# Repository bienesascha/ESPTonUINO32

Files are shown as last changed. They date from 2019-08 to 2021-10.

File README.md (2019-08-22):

# ESPTonUINO32
*ESPTonUINO32 V3.1.1 by M.Schwager*

- orginal [TonUINO-ESP32](http://discourse.voss.earth/t/esp32-port-inkl-webinterface/399)
_[TonUINO V2.0](https://www.voss.earth/tonuino/) Code for ESP32 with extensions, there is also [Discourse Seite](http://discourse.voss.earth/)_
- TonUNI-ESP32 V3.1 by C.Ulbrich, 

## *actual under development*
 - additional buttons
   - seperate buttons for next/last track / 5 button control

 - SDCard files  
   - Language menu and structure expanded to Tag to save Ambilight color
   - additional files added
   - sorting mp3 files

 - electric
   - actual schema
   - actual layout

 - 3d housing

**Currently implemented:**
  
  - Web interface for remote control
    - Play, Pause, Start, Stop, Volume
    - Adjust equalizer
    - max. Adjust Volume
    - Off timer
    - On timer
    
  - Ambientlight with WS2812 LEDss
    - change the color via web interface
    
  - Timer for switching on and off
    - Sunrise and sunset simulation for switch-on timer
    - MP3 playback when switching on / off
    
  - AP mode to configure WLAN without anchoring this (SSID, PW) in the code
    - Voice message if there is an error with the connection
   
  - Welcome at startup 
   
  - Headphone detection
    - reduces the volume when headphones plugged
    - Limit the volume when headphones are plugged
    - switches to previous volume when headphones are no longer plugged in
      
  - Function of the up-down keys changed
    - short press = Volume +/-
    - long press = Track +/- (unused if 5 buttons enabled)

  - Viual Studio Code mit platformio-code
    
 **Hardware / Layout**
  (http://hobbycomponents.com/images/forum/Wemos_Lolin_D32_Diagram_HCWEMO0014.png)
 
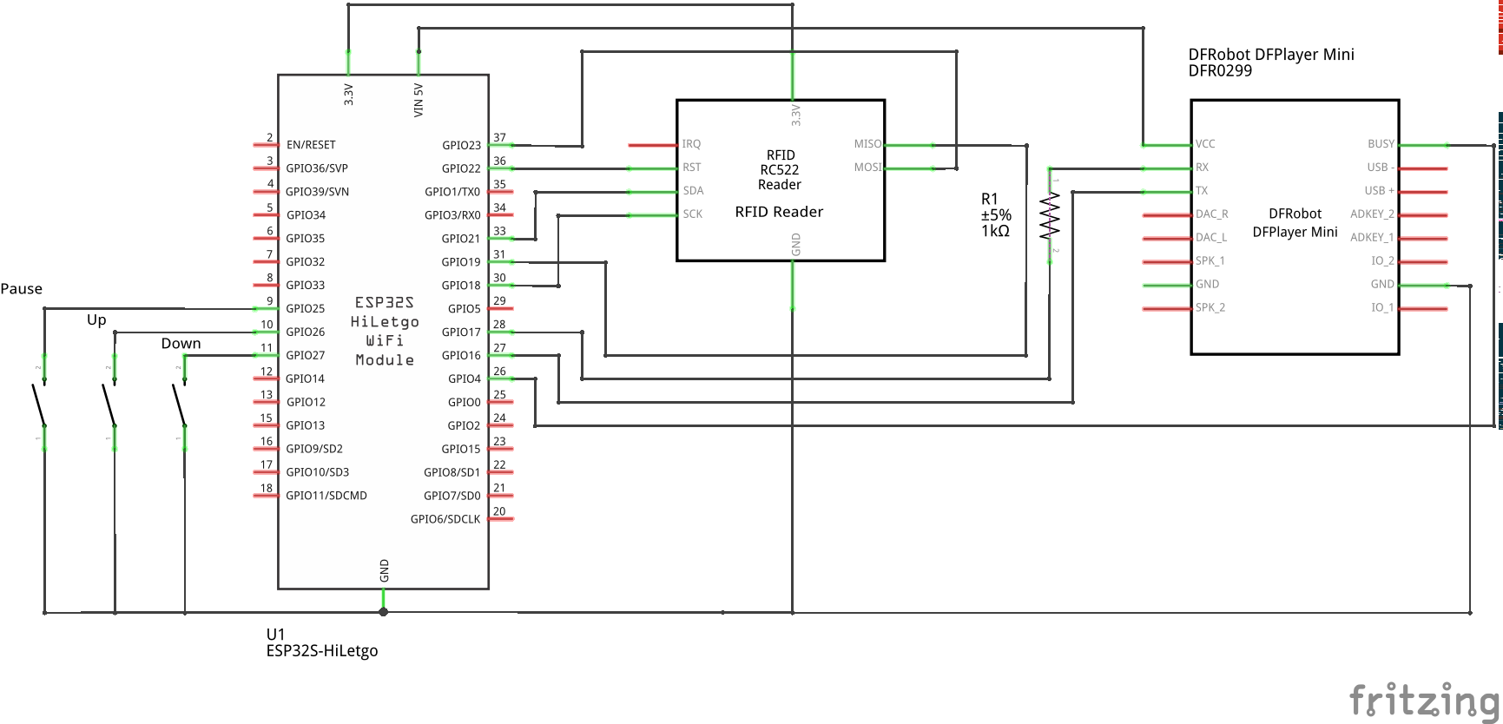
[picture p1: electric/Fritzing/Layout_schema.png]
fritzing Layout
 
 
 **Still open and planned:**
 
  - Saving the settings in EEPROM / Flash
  - Manage tags

  **additional goodies**

   - precompiles bin file

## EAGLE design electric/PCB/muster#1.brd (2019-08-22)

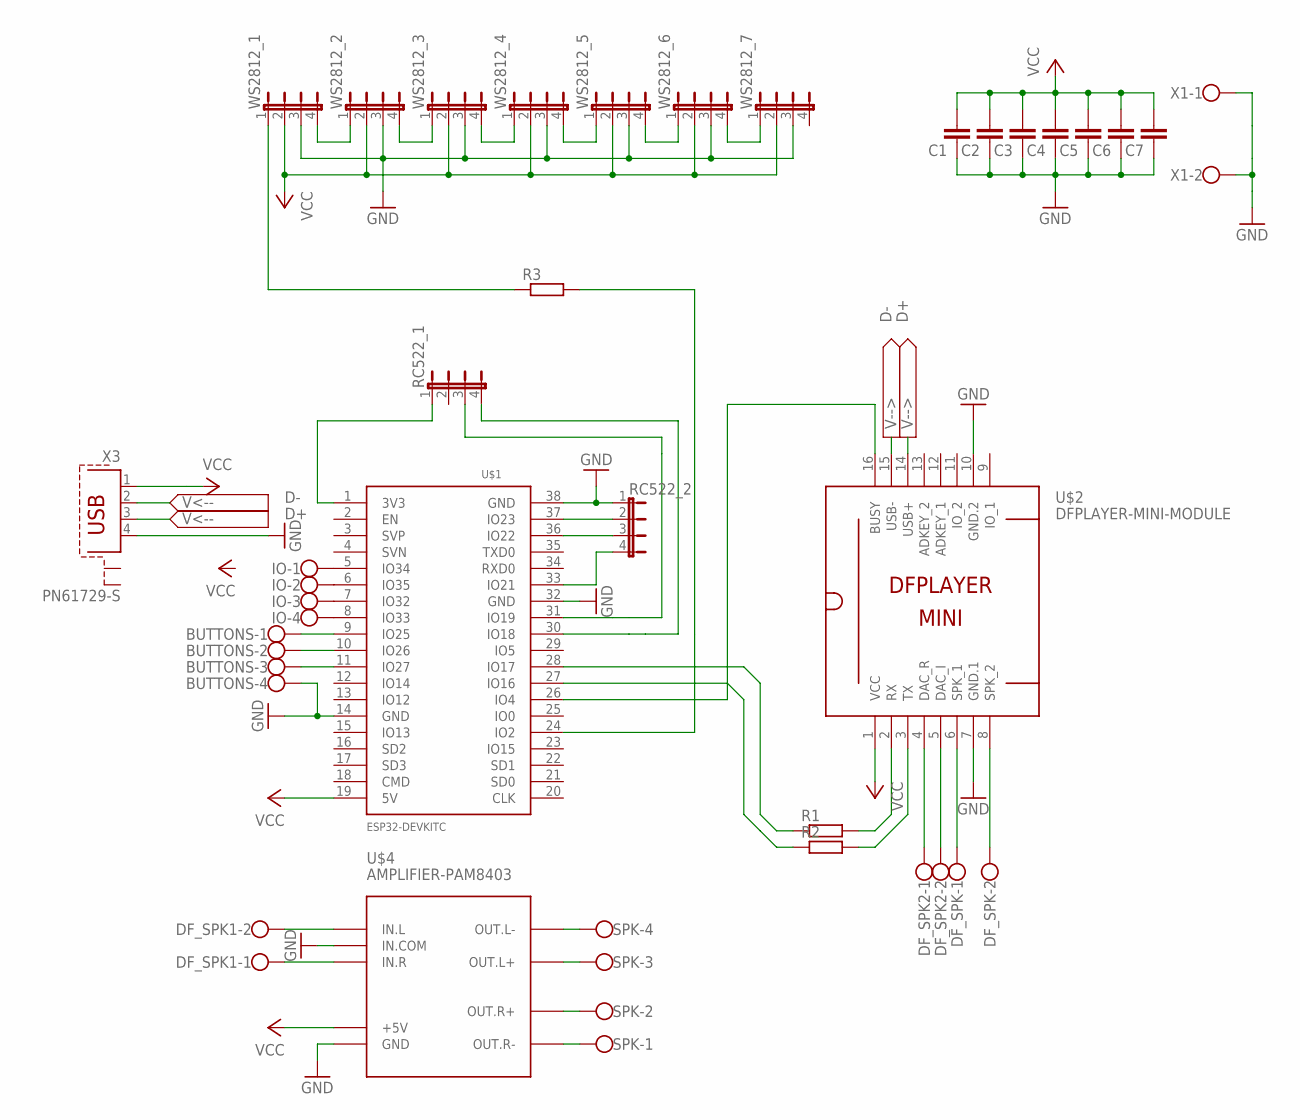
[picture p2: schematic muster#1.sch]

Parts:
BUTTONS: W237-4
C1: C-EU025-024X044; C025-024X044
C2, C3, C4, C5, C6, C7: C-EU025-025X050; C025-025X050
DF_SPK, DF_SPK1, DF_SPK2: W237-02P; W237-132
IO: W237-4
R1, R2, R3: R-EU_0204/2V; 0204V
RC522_1, RC522_2: JP4E; JP4
SPK: W237-4
U$1: ESP32DEVKITC; ESP32-DEVKITC
U$2: DFPLAYER-MINI-MODULE
U$4: AMPLIFIER-PAM8403
WS2812_1, WS2812_2, WS2812_3, WS2812_4, WS2812_5, WS2812_6, WS2812_7: JP4E; JP4
X1: W237-102
X3: PN61729-S

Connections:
D+: U$2.14 (USB+), X3.3
D-: U$2.15 (USB-), X3.2
GND: BUTTONS.4, C1.1, C2.1, C3.1, C4.1, C5.1, C6.1, C7.1, RC522_2.1, U$1.14 (GND), U$1.32 (GND), U$1.38 (GND), U$2.7 (GND.1), U$2.10 (GND.2), U$4.GND, U$4.IN.COM, WS2812_1.3, WS2812_2.3, WS2812_3.3, WS2812_4.3, WS2812_5.3, WS2812_6.3, WS2812_7.3, X1.1, X1.2, X3.4
unnamed: DF_SPK.2, U$2.8 (SPK_2)
unnamed: DF_SPK.1, U$2.6 (SPK_1)
unnamed: BUTTONS.1, U$1.9 (IO25)
unnamed: BUTTONS.2, U$1.10 (IO26)
unnamed: BUTTONS.3, U$1.11 (IO27)
unnamed: R1.1, U$1.28 (IO17)
unnamed: R2.1, U$1.27 (IO16)
unnamed: R2.2, U$2.3 (TX)
unnamed: WS2812_1.4, WS2812_2.1
unnamed: WS2812_2.4, WS2812_3.1
unnamed: R1.2, U$2.2 (RX)
unnamed: SPK.1, U$4.OUT.R-
unnamed: DF_SPK2.1, U$2.4 (DAC_R)
unnamed: R3.1, WS2812_1.1
unnamed: SPK.2, U$4.OUT.R+
unnamed: SPK.3, U$4.OUT.L+
unnamed: SPK.4, U$4.OUT.L-
unnamed: WS2812_3.4, WS2812_4.1
unnamed: WS2812_4.4, WS2812_5.1
unnamed: WS2812_5.4, WS2812_6.1
unnamed: WS2812_6.4, WS2812_7.1
unnamed: DF_SPK2.2, U$2.5 (DAC_I)
unnamed: DF_SPK1.2, U$4.IN.L
unnamed: DF_SPK1.1, U$4.IN.R
unnamed: R3.2, U$1.24 (IO2)
unnamed: RC522_2.2, U$1.37 (IO23)
unnamed: U$1.26 (IO4), U$2.16 (BUSY)
unnamed: RC522_2.3, U$1.36 (IO22)
unnamed: RC522_2.4, U$1.33 (IO21)
unnamed: RC522_1.3, U$1.31 (IO19)
unnamed: RC522_1.4, U$1.30 (IO18)
unnamed: RC522_1.1, U$1.1 (3V3)
unnamed: IO.1, U$1.5 (IO34)
unnamed: IO.2, U$1.6 (IO35)
unnamed: IO.3, U$1.7 (IO32)
unnamed: IO.4, U$1.8 (IO33)
VCC: C1.2, C2.2, C3.2, C4.2, C5.2, C6.2, C7.2, U$1.19 (5V), U$2.1 (VCC), U$4.+5V, WS2812_1.2, WS2812_2.2, WS2812_3.2, WS2812_4.2, WS2812_5.2, WS2812_6.2, WS2812_7.2, X3.1

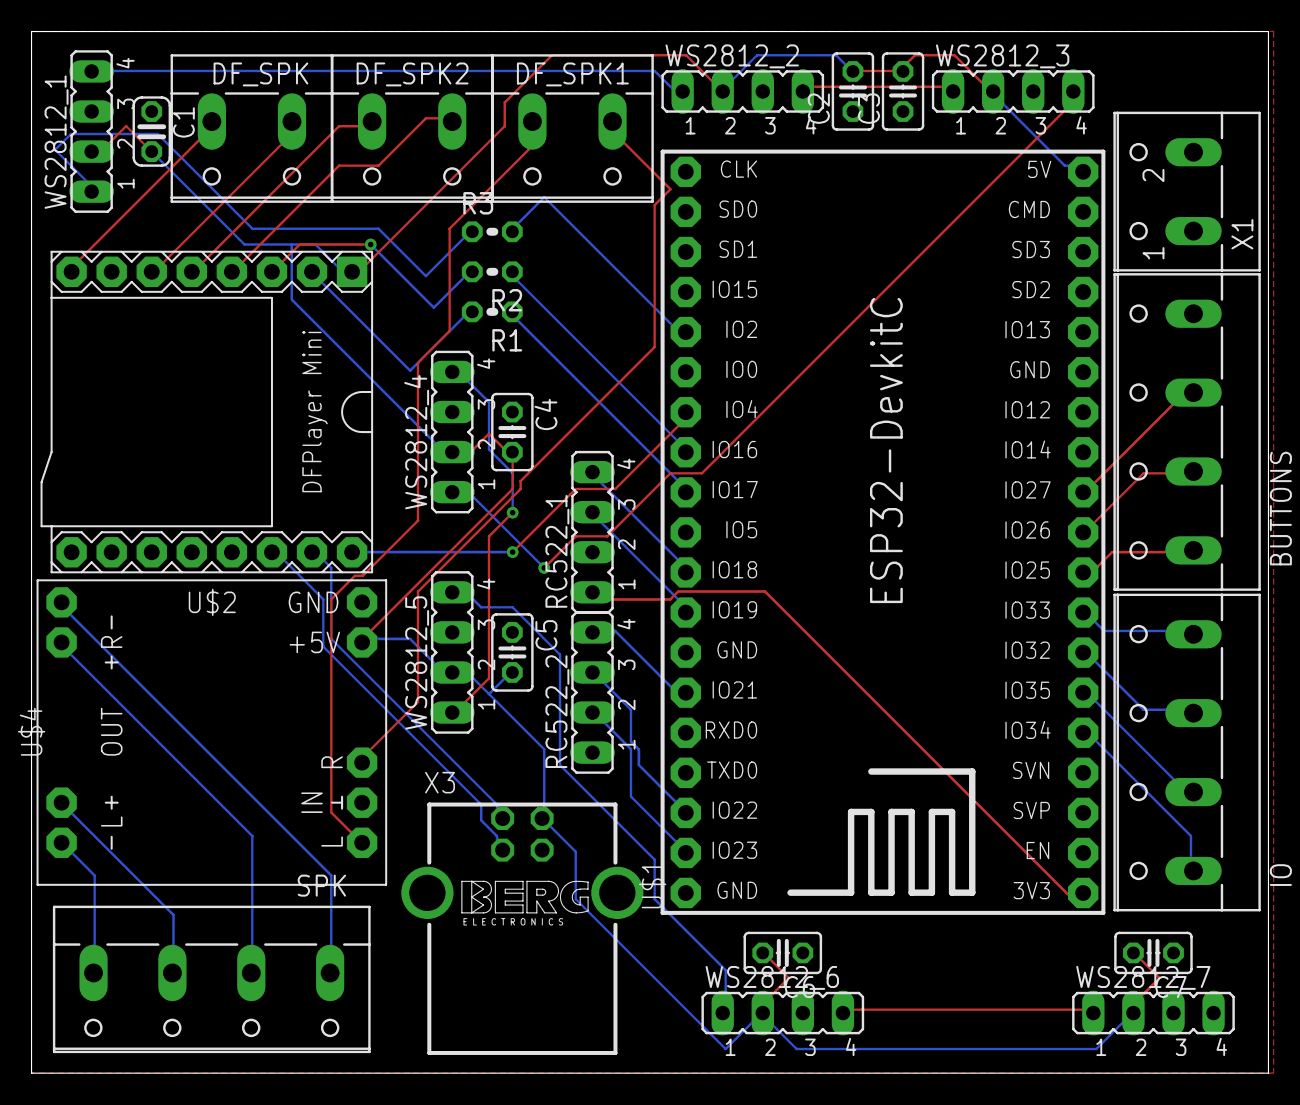
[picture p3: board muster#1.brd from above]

Board: 2 copper layers, 78.4 x 66.0 mm, 30 parts (0 on the bottom side), 40 nets.

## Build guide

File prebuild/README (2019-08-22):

This directory is only for pre-compiled-builds.

No warranty, no hardware checks

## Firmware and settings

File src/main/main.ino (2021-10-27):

//==================================================================
// ESPTonUINO32 V4.0.1 of ESP Lolin32
// changed by Sascha Ludwig
// 2021-10
// Original V2.0: T. Voss, Erweitert V3.0: C. Ulbrich
//------------------------------------------------------------------
// the DIY jukebox (not only) for kids
//
// Take an ESP lolin32, an MP3 module (DFPlayer mini), an RFID reader (RC522), 
// a micro SD card, Resistor, 3-5 buttons
// some cables and an old (or new) bookshelf speaker maybe a lipo bat...
// and you have the ESPTonUINO32 with charge controll and bat power
//==================================================================

// Used libraries

#include <WiFi.h>
#include <NTPClient.h>
#include <WiFiUdp.h>
#include "TonUINO_html.h"         // German version of html page
#include "TonUINO.h"  
#include <Arduino.h>
#include "DFRobotDFPlayerMini.h"
#include <SPI.h>
#include <MFRC522.h>
#include <EEPROM.h>
#include <JC_Button.h>
#include <math.h>
#include <FastLED.h>
#include <Update.h>
#include <WebServer.h>
#include <Preferences.h>
#include "define.h"

// EEPROM Storage *NVS*
// EEPROM_SIZE = EEPROM.length(); KO for ESP32
#define EEPROM_SIZE 4096
Preferences preferences;
int timeout = 20;

//========================================================================
// Only variables for testing
int l = 0;
bool headphoneIn = 1; //0;
int success = 0;
int success2 = 0;

bool debug = false; //false // Set to "true" to get debug information via the serial port.

//Variables for saving settings
//========================================================================
unsigned long last_color = 0xFFFFFF;
unsigned int last_Volume;
unsigned int last_max_Volume;

CRGB leds[NUM_LEDS];

//============Sunrise Variables===========================================
DEFINE_GRADIENT_PALETTE( sunrise_gp ) {
  0,     0,  0,  0,             // black
  128,   240,  0,  0,           // red
  224,   240, 240,  0,          // yellow
  255,   128, 128, 240
}; //very bright blue
static uint16_t heatIndex = 0; // start out at 0

//========================================================================
//NTP Variables
WebServer server(80);
WiFiUDP ntpUDP;
NTPClient timeClient(ntpUDP);

//========================================================================
// Added code line to PCD_Init() (MFRC522.cpp) :
//  PCD_WriteRegister(RFCfgReg, (0x07<<4)); // Set Rx Gain to max
// Before :
//  PCD_AntennaOn();
//========================================================================


//Created object for communication with the module
MFRC522 mfrc522 = MFRC522(SS_PIN, RESET_PIN); // Create instance

Button pauseButton(buttonPause);
Button upButton(buttonUp, 100);
Button downButton(buttonDown, 100);

bool ignorePauseButton = false;
bool ignoreUpButton = false;
bool ignoreDownButton = false;

#if defined fiveButtons
  Button nextButton(buttonNext, 100);
  Button lastButton(buttonLast, 100);
  bool nextButton = false;
  bool lastButton = false;
#endif

//=======================Functions Declaration==============================
nfcTagObject myCard;
bool knownCard = false;
uint16_t numTracksInFolder;
uint16_t track;
uint64_t chipid;

MFRC522::MIFARE_Key key;
bool successRead;
byte sector = 1;
byte blockAddr = 4;
byte trailerBlock = 7;
MFRC522::StatusCode status;

uint8_t numberOfCards = 0;

//====================Timer Declaration=====================================
hw_timer_t * timer = NULL;
volatile SemaphoreHandle_t timerSemaphore;
portMUX_TYPE timerMux = portMUX_INITIALIZER_UNLOCKED;

volatile uint32_t isrCounter = 0;
volatile boolean isrRead = true;

void IRAM_ATTR onTimer() {
  // Increment the counter and set the time of ISR
  portENTER_CRITICAL_ISR(&timerMux);
  isrCounter++;
  isrRead = false;
  portEXIT_CRITICAL_ISR(&timerMux);
  // Give a semaphore that we can check in the loop
  xSemaphoreGiveFromISR(timerSemaphore, NULL);
  // It is safe to use digitalRead/Write here if you want to toggle an output
}

// implement a notification class,
// its member methods will get called
//
class Mp3Notify {
  public:
    static void OnError(uint16_t errorCode) {
      // see DfMp3_Error for code meaning
      Serial.println();
      Serial.print("Com Error ");
      Serial.println(errorCode);
      switchOnLeds(NUM_LEDS, KO_COLOR );
    }
    static void OnPlayFinished(uint16_t track) {
      Serial.print("Track finished");
      Serial.println(track);
      delay(100);
      nextTrack();
    }
    static void OnCardOnline(uint16_t code) {
      Serial.println(F("SD card online "));
    }
    static void OnCardInserted(uint16_t code) {
      Serial.println(F("SD card ready "));
    }
    static void OnCardRemoved(uint16_t code) {
      Serial.println(F("SD card removed "));
      switchOnLeds(NUM_LEDS, KO_COLOR );
    }
};

HardwareSerial mySoftwareSerial(2);
DFRobotDFPlayerMini myDFPlayer;

// Unfortunately, the module can not play a queue
static void nextTrack() {
  if (knownCard == false)
    // When a new card is learned, the end of a track should not be processed
    return;

  if (myCard.mode == 1) {
    Serial.println(F("Radio play mode is active -> save power"));
    myDFPlayer.sleep();
  }
  if (myCard.mode == 2) {
    if (track != numTracksInFolder) {
      track = track + 1;
      playFolder(myCard.folder, track);
      Serial.print(F("Album mode is active -> next track: "));
      Serial.print(track);
    } else
      myDFPlayer.sleep();
  }
  if (myCard.mode == 3) {
    track = random(1, numTracksInFolder + 1);
    Serial.print(F("Party mode is active -> play random track: "));
    Serial.println(track);
    playFolder(myCard.folder, track);
  }
  if (myCard.mode == 4) {
    Serial.println(F("Single mode active -> save power"));
    myDFPlayer.sleep();
  }
  if (myCard.mode == 5) {
    if (track != numTracksInFolder) {
      track = track + 1;
      Serial.print(F("Audiobook mode is active -> next track and save progress"));
      Serial.println(track);
      playFolder(myCard.folder, track);
      // Save progress in the EEPROM
      EEPROM.write(myCard.folder, track);
    } else
      myDFPlayer.sleep();
    // Reset progress
    EEPROM.write(myCard.folder, 1);
  }
  delay(500);
}

static void previousTrack() {
  if (myCard.mode == 1) {
    Serial.println(F("Radio play mode is active -> play track from the beginning"));
    playFolder(myCard.folder, track);
  }
  if (myCard.mode == 2) {
    Serial.println(F("Album mode is active -> Previous track"));
    if (track != 1) {
      track = track - 1;
    }
    playFolder(myCard.folder, track);
  }
  if (myCard.mode == 3) {
    Serial.println(F("Party Modus is active -> Play track from the beginning"));
    playFolder(myCard.folder, track);
  }
  if (myCard.mode == 4) {
    Serial.println(F("Single mode active -> Play track from the beginning"));
    playFolder(myCard.folder, track);
  }
  if (myCard.mode == 5) {
    Serial.println(F("Audiobook mode is active -> Next track and save progress"));
    if (track != 1) {
      track = track - 1;
    }
    playFolder(myCard.folder, track);
    // Save progress in the EEPROM
    EEPROM.write(myCard.folder, track);
  }
}

bool isPlaying() {
  return !digitalRead(busyPin);
}

//==========================================================================================
// Function to evaluate the answers of the HTML page
void handleRestart() {
  // Restart ESP
  ESP.restart();
}

void handleUpdate() {
  server.send(200, "text/html", UpdatePage());
}

void handleSetup() {
  server.send ( 200, "text/html", SetupPage());
  if (server.args() > 0 ) { // Arguments were received
    for ( uint8_t i = 0; i < server.args(); i++ ) {

      Serial.print("The server received the following: "); // Display the argument
      Serial.print(server.argName(i)); // Display the argument
      Serial.print("=");
      Serial.println(server.arg(i));

      if (server.argName(i) == "ssid" ) {
        Serial.print("saved SSID : '");
        Serial.println(server.arg(i));
        preferences.putString("SSID", server.arg(i));

      }

      else if (server.argName(i) == "pw") {
        Serial.print("saved PW : '");
        Serial.println(server.arg(i));
        preferences.putString("Password", server.arg(i));

      } else if (server.argName(i) == "hostname") {
        Serial.print("saved Hostname: ");
        Serial.println(server.arg(i));
        preferences.putString("Hostname", server.arg(i));

      }
    }
  }
}

void handleRoot() {
  server.send ( 200, "text/html", getPage() );
  if (server.args() > 0 ) { // Arguments were received
    for ( uint8_t i = 0; i < server.args(); i++ ) {

      Serial.print("The server received the following: "); // Display the argument
      Serial.print(server.argName(i)); // Display the argument
      Serial.print("=");
      Serial.println(server.arg(i));

      if (server.argName(i) == "appt-time-off" ) {
        TimerOFF = server.arg(i);
        char charBuf[TimerOFF.length() + 1];
        TimerOFF.toCharArray(charBuf, TimerOFF.length() + 1);
        TMR_OFF_HH = atof(strtok(charBuf, ":"));
        TMR_OFF_MM = atof(strtok(NULL, ":"));
        Serial.print("The time read in for TimerOFF: ");
        Serial.print(TMR_OFF_HH);
        Serial.print(":");
        Serial.println(TMR_OFF_MM);
        TMR_OFF_REP = 0;
        TMP_OFFTIME = false;
      }

      else if (server.argName(i) == "cb_tmr_off") {
        TMR_OFF_REP = 1;
        Serial.println("A repeat has been set for the TimerOFF");
      }

      else if (server.argName(i) == "appt-time-on") {
        TimerON = server.arg(i);
        char charBuf[TimerON.length() + 1];
        TimerON.toCharArray(charBuf, TimerON.length() + 1);
        TMR_ON_HH = atof(strtok(charBuf, ":"));
        TMR_ON_MM = atof(strtok(NULL, ":"));
        Serial.print("The time read in for TimerON: ");
        Serial.print(TMR_ON_HH);
        Serial.print(":");
        Serial.println(TMR_ON_MM);
        TMR_ON_REP = 0;
        TMP_ONTIME = false;
      }

      else if (server.argName(i) == "cb_tmr_on") {
        TMR_ON_REP = 1;
        Serial.println("A repetition has been set for the TimerON");
      }

      else if (server.argName(i) == "akt_volume") {
        myDFPlayer.volume(server.arg(i).toInt());
        akt_Volume = myDFPlayer.readVolume();
        Serial.println("The current volume level has been changed");
      }
      else if (server.argName(i) == "max_volume") {
        max_Volume = server.arg(i).toInt();
        Serial.println("The maximum volume level has been changed");
      }
      else if (server.argName(i) == "LED_color") {
        Serial.println("The color of the LEDs is changed: " + server.arg(i));
        String Color = server.arg(i);
        char *ptr;
        char charBuf[Color.length() + 1];
        Color.toCharArray(charBuf, Color.length() + 1);
        unsigned long col = strtol(charBuf, &ptr, 16);
        switchOnLeds(NUM_LEDS, col );
      }
      else if (server.argName(i) == "LED_bri") {
        Serial.println("The brightness of the LEDs is changed ");
        Serial.println("brightness = " + server.arg(i));
        FastLED.setBrightness(server.arg(i).toInt());
        FastLED.show();
      }
      else if (server.argName(i) == "cb_SleepLight_on") {
        //CODE HERE
        if (server.arg(i).toInt() == 1) {
          SleepLight = true;
        }
      }
      else if (server.argName(i) == "cb_SleepLight_off") {
        if (server.arg(i).toInt() == 0) {
          SleepLight = false;
        }
      }
      else if (server.argName(i) == "cb_WakeUpLight_on") {
        if (server.arg(i).toInt() == 1) {
          WakeUpLight = true;
        }

      }
      else if (server.argName(i) == "cb_WakeUpLight_off") {
        if (server.arg(i).toInt() == 0) {
          WakeUpLight = false;
        }
      }

    }
  }
}

//===================================================================================
// From here, actions which are triggered by pressing a button on the HTML page
void handlePrev() {
  Serial.println("handlePrev");
  myDFPlayer.previous();
  server.send(200, "text/html", getPage());
}

void handlePlay() {
  Serial.println("handlePlay");
  myDFPlayer.start();
  server.send(200, "text/html", getPage());
}

void handlePause() {
  Serial.println("handlePause");
  myDFPlayer.pause();
  server.send(200, "text/html", getPage());
}

void handleNext() {
  Serial.println("handleNext");
  myDFPlayer.next();
  server.send(200, "text/html", getPage());
}

void handleVol_up() {
  Serial.println("handleVol+");
  myDFPlayer.volumeUp();
  akt_Volume = myDFPlayer.readVolume();
  server.send(200, "text/html", getPage());
}

void handleVol_down() {
  Serial.println("handleVol-");
  myDFPlayer.volumeDown();
  akt_Volume = myDFPlayer.readVolume();
  server.send(200, "text/html", getPage());
}

void handleEQ_NORM() {
  Serial.println("handleEQ_Norm");
  myDFPlayer.EQ(DFPLAYER_EQ_NORMAL);
  server.send(200, "text/html", getPage());
}

void handleEQ_POP() {
  Serial.println("handleEQ_POP");
  myDFPlayer.EQ(DFPLAYER_EQ_POP);
  server.send(200, "text/html", getPage());
}

void handleEQ_ROCK() {
  Serial.println("handleEQ_ROCK");
  myDFPlayer.EQ(DFPLAYER_EQ_ROCK);
  server.send(200, "text/html", getPage());
}

void handleEQ_CLASSIC() {
  Serial.println("handleEQ_CLASSIC");
  myDFPlayer.EQ(DFPLAYER_EQ_CLASSIC);
  server.send(200, "text/html", getPage());
}

void handleEQ_BASS() {
  Serial.println("handleEQ_BASE");
  myDFPlayer.EQ(DFPLAYER_EQ_BASS);
  server.send(200, "text/html", getPage());
}

void handleEQ_JAZZ() {
  Serial.println("handleEQ_JAZZ");
  myDFPlayer.EQ(DFPLAYER_EQ_JAZZ);
  server.send(200, "text/html", getPage());
}
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
void loop() {
  do {

    if (xSemaphoreTake(timerSemaphore, 0) == pdTRUE) { //Timer Interrupt Routine
      uint32_t isrCount = 0, isrTime = 0;
      // Read the interrupt count and time
      portENTER_CRITICAL(&timerMux);
      isrCount = isrCounter;
      if (isrRead == false) {
        isrRead = true;
        isrTime = millis();
      }
      portEXIT_CRITICAL(&timerMux);
      //From here functions for timers

      if (success == 1) TimeCompare(); //Query time in seconds
      if (startSR == true) sunrise();

    }
    server.handleClient();

    if (!isPlaying()) {
      if (myDFPlayer.available()) {
        printDetail(myDFPlayer.readType(), myDFPlayer.read()); //Print the detail message from DFPlayer to handle different errors and states.
      }
    }
    // Buttons are now traded via JS_Button, so that each key can be assigned twice
    pauseButton.read();
    upButton.read();
    downButton.read();

    // Detecting if a headphone is plugged in, "headphoneIn" locks in each case the query so that it will go through only once
    if ((digitalRead(headphonePin) == 1) && (headphoneIn == 0)) {

      Serial.println("Earphone was plugged in");
      digitalWrite(dfpMute, HIGH);
      headphoneIn = 1;
      last_max_Volume = max_Volume; // Remember the last maximum volume
      last_Volume = myDFPlayer.readVolume();
      max_Volume = max_Volume_headphone;
      if (myDFPlayer.readVolume() >= max_Volume) {
        Serial.print("myDFPlayer.readVolume : ");
        Serial.print(myDFPlayer.readVolume());
        Serial.print(" >= max_Volume : ");
        Serial.println(max_Volume);
        myDFPlayer.volume(max_Volume_headphone);
      }

    } else if ((digitalRead(headphonePin) == 0) && (headphoneIn == 1)) {
      Serial.println("Headphones have been removed");
      headphoneIn = 0;
      max_Volume = last_max_Volume;
      myDFPlayer.volume(last_Volume);
    }

    if (pauseButton.wasReleased()) {
      if (ignorePauseButton == false) {
        if (isPlaying()) {
          myDFPlayer.pause();
          switchOnLeds(NUM_LEDS, CRGB::Black );
          startSR = false;
          heatIndex = 0;
        } else {
          myDFPlayer.start();

          ignorePauseButton = false;
        }
      }
    } else if (pauseButton.pressedFor(LONG_PRESS) &&
               ignorePauseButton == false) {
      Serial.println(F("Pause button was pressed long"));
      if (isPlaying()) {
        myDFPlayer.advertise(track);
      }
      else {
        knownCard = false;
        playMp3Folder(800);
        resetCard();
        mfrc522.PICC_HaltA();
        mfrc522.PCD_StopCrypto1();
      }
      ignorePauseButton = true;
    }

    if (upButton.pressedFor(LONG_PRESS)) {
      Serial.println(F("Volume Up"));
      myDFPlayer.volumeUp();
      nextTrack();
      ignoreUpButton = true;
      delay(1000);
    } else if (upButton.wasReleased()) {
      if (!ignoreUpButton) {
        //nextTrack();
        if (myDFPlayer.readVolume() <= max_Volume) {
          myDFPlayer.volumeUp();
        }
      } else {
        ignoreUpButton = false;
      }
    }

    if (downButton.pressedFor(LONG_PRESS)) {
      Serial.println(F("Volume Down"));
      myDFPlayer.volumeDown();
      previousTrack();
      ignoreDownButton = true;
      delay(1000);
    } else if (downButton.wasReleased()) {
      if (!ignoreDownButton)
        //previousTrack();
        myDFPlayer.volumeDown();
      else
        ignoreDownButton = false;
    }

    // End of the buttons
  } while (!mfrc522.PICC_IsNewCardPresent());

  // RFID card was launched

  if (!mfrc522.PICC_ReadCardSerial())
    return;

  if (readCard(&myCard) == true) {
    if (myCard.cookie == 322417479 && myCard.folder != 0 && myCard.mode != 0) {

      knownCard = true;
      numTracksInFolder = myDFPlayer.readFileCountsInFolder(myCard.folder);
      
      Serial.println(F("----------------------------------------"));
      Serial.print(F("| myCard.folder     : "));
      Serial.println(myCard.folder);
      Serial.print(F("| numTracksInFolder : "));
      Serial.println(numTracksInFolder);
      Serial.print(F("| myCard.mode       : "));
      Serial.println(myCard.mode);
      Serial.print(F("| myCard.color      : "));
      Serial.println(myCard.color);
      Serial.println(F("----------------------------------------"));

      // Radio play mode: a random file from the folder
      if (myCard.mode == 1) {
        Serial.println(F("Radio play mode -> play random track"));
        track = random(1, numTracksInFolder + 1);
        Serial.println(track);
      }
      // Album mode: play complete folder
      if (myCard.mode == 2) {
        Serial.println(F("Album mode -> play complete folder"));
        track = 1;
      }
      // Party Mode: Folder in random order
      if (myCard.mode == 3) {
        Serial.println(F("Party Mode -> play folders in random order"));
        track = random(1, numTracksInFolder + 1);
      }
      // Single mode: play a file from the folder
      if (myCard.mode == 4) {
        Serial.println(F("Single mode -> play a file from the folder"));
        track = myCard.special;
      }
      // Audiobook mode: play complete folder and remember progress
      if (myCard.mode == 5) {
        Serial.println(F("Audiobook mode -> play complete folder and remember progress"));
        track = EEPROM.read(myCard.folder);
        if (track == 0)track = 1;
      }
      playFolder(myCard.folder, track);
      switchOnLeds(NUM_LEDS, myCard.color );
    }

    // New card configured
    else {
      knownCard = false;
      setupCard();
    }
  }
  mfrc522.PICC_HaltA();
  mfrc522.PCD_StopCrypto1();
}
//==============END LOOP================================


//==========================================================================================
// Function voiceMenu
int voiceMenu(int numberOfOptions, int startMessage, int messageOffset,
              bool preview , int previewFromFolder) {
  int returnValue = 0;

  Serial.println(F("Will play file no.:"));
  Serial.println(startMessage);

  if (startMessage != 0) {
    playMp3Folder(startMessage);
    playMp3Folder(startMessage);
  }
  do {
    pauseButton.read();
    upButton.read();
    downButton.read();
    //myDFPlayer.loop();
    if (pauseButton.wasPressed()) {
      if (returnValue != 0)
        return returnValue;
      delay(1000);
    }

    if (upButton.pressedFor(LONG_PRESS)) {
      returnValue = fmin(returnValue + 10, numberOfOptions);
      playMp3Folder(messageOffset + returnValue);
      delay(1000);
      if (preview) {
        do {
          delay(10);
        } while (isPlaying());
        if (previewFromFolder == 0)
          playFolder(returnValue, 1);
        else
          playFolder(previewFromFolder, returnValue);
      }
      ignoreUpButton = true;
    } else if (upButton.wasReleased()) {
      if (!ignoreUpButton) {
        returnValue = fmin(returnValue + 1, numberOfOptions);
        playMp3Folder(messageOffset + returnValue);
        delay(1000);
        if (preview) {
          do {
            delay(10);
          } while (isPlaying());
          if (previewFromFolder == 0)
            playFolder(returnValue, 1);
          else
            playFolder(previewFromFolder, returnValue);
        }
      } else
        ignoreUpButton = false;
    }

    if (downButton.pressedFor(LONG_PRESS)) {
      returnValue = fmax(returnValue - 10, 1);
      playMp3Folder(messageOffset + returnValue);
      delay(1000);
      if (preview) {
        do {
          delay(10);
        } while (isPlaying());
        if (previewFromFolder == 0)
          playFolder(returnValue, 1);
        else
          playFolder(previewFromFolder, returnValue);
      }
      ignoreDownButton = true;
    } else if (downButton.wasReleased()) {
      if (!ignoreDownButton) {
        returnValue = fmax(returnValue - 1, 1);
        playMp3Folder(messageOffset + returnValue);
        delay(1000);
        if (preview) {
          do {
            delay(10);
          } while (isPlaying());
          if (previewFromFolder == 0)
            playFolder(returnValue, 1);
          else
            playFolder(previewFromFolder, returnValue);
        }
      } else
        ignoreDownButton = false;
    }
  } while (true);
}
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

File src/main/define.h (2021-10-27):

//define-files 
// version 4.0.1 by Sascha Ludwig 2021-10-27
//
/*
struct card {
  int folder=0;
  int track=0;
  uint32_t cardID=0;
  int numTracksInFolder=0;
};

union ArrayToInteger {
  byte array[4];
 uint32_t integer;
};
*/

// KY 040
//========================================================================
// #define PIN_A   26 //ky-040 clk pin, interrupt & add 100nF/0.1uF capacitors between pin & ground!!!
// #define PIN_B   25 //ky-040 dt  pin,             add 100nF/0.1uF capacitors between pin & ground!!!
// #define BUTTON  27 //ky-040 sw  pin, interrupt & add 100nF/0.1uF capacitors between pin & ground!!!

// normal Buttons
#define buttonPause 25
#define buttonUp 26
#define buttonDown 27

//#define fiveButtons
#if defined fiveButtons
   #define buttonNext 32
   #define buttonLast 33
#endif

#define LONG_PRESS 1000

//WS2812b settings
#define DATA_PIN 2        // signal pin 
#define NUM_LEDS 24       // number of LEDs in your strip
#define BRIGHTNESS 32     // brightness  (max 254) 
#define LED_TYPE WS2812B  // I know we are using ws2812, but it's ok!
#define COLOR_ORDER GRB   // Datasheet WS2812 : "Follow the order of GRB to sent data"
#define OK_COLOR CRGB::Green
#define KO_COLOR CRGB::Red
#define WARNING_COLOR CRGB::Orange

//Set Pins for Dfplayer Mini Module
#define busyPin 4
#define headphonePin 32
#define dfpMute 33
#define RX_PIN 16
#define TX_PIN 17

//Set Pins for RC522 Module
#define RESET_PIN 22     // Reset pin 
#define SS_PIN 21        // Slave select pin 

// ================================================
// Parameter
// ================================================
#define GND_SWI_PIN GPIO_NUM_12

//Variable for reading the HTML response
String TimerOFF = "00:00";
String TimerON = "00:00";
uint8_t TMR_OFF_HH, TMR_OFF_MM, TMR_ON_HH, TMR_ON_MM;
int TMR_OFF_REP = 0;
int TMR_ON_REP = 0;
unsigned int max_Volume = 40;
unsigned int akt_Volume = 10;
unsigned int init_Volume = 12; //Set volume value (0~30).
unsigned int max_Volume_headphone = 35;

bool TMP_OFFTIME = false;
bool TMP_ONTIME = false;
bool WakeUpLight = false;
bool SleepLight = false;
bool startSR = false;        // Bool to start Sunrise simulation

#define DEEPSLEEP_WAKEUP_PIN GPIO_NUM_14

#define AUTOSLEEP_TIME 420000 //900000UL //15min

const char* PARAM_MESSAGE = "folder";

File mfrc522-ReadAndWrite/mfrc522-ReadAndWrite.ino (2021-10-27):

/**
 * ----------------------------------------------------------------------------
 * This is a MFRC522 library example; see https://github.com/miguelbalboa/rfid
 * for further details and other examples.
 *
 * NOTE: The library file MFRC522.h has a lot of useful info. Please read it.
 *
 * Released into the public domain.
 * ----------------------------------------------------------------------------
 * This sample shows how to read and write data blocks on a MIFARE Classic PICC
 * (= card/tag).
 *
 * BEWARE: Data will be written to the PICC, in sector #1 (blocks #4 to #7).
 *
 *
 * Typical pin layout used:
 * -----------------------------------------------------------------------------------------
 *             MFRC522      Arduino       Arduino   Arduino    Arduino          Arduino
 *             Reader/PCD   Uno/101       Mega      Nano v3    Leonardo/Micro   Pro Micro
 * Signal      Pin          Pin           Pin       Pin        Pin              Pin
 * -----------------------------------------------------------------------------------------
 * RST/Reset   RST          9             5         D9         RESET/ICSP-5     RST
 * SPI SS      SDA(SS)      10            53        D10        10               10
 * SPI MOSI    MOSI         11 / ICSP-4   51        D11        ICSP-4           16
 * SPI MISO    MISO         12 / ICSP-1   50        D12        ICSP-1           14
 * SPI SCK     SCK          13 / ICSP-3   52        D13        ICSP-3           15
 *
 */

#include <SPI.h>
#include <MFRC522.h>

#define RST_PIN         22           // Configurable, see typical pin layout above
#define SS_PIN          21          // Configurable, see typical pin layout above

MFRC522 mfrc522(SS_PIN, RST_PIN);   // Create MFRC522 instance.

MFRC522::MIFARE_Key key;

/**
 * Initialize.
 */
void setup() {
    Serial.begin(115200); // Initialize serial communications with the PC
    while (!Serial);    // Do nothing if no serial port is opened (added for Arduinos based on ATMEGA32U4)
    SPI.begin();        // Init SPI bus
    mfrc522.PCD_Init(); // Init MFRC522 card

    // Prepare the key (used both as key A and as key B)
    // using FFFFFFFFFFFFh which is the default at chip delivery from the factory
    for (byte i = 0; i < 6; i++) {
        key.keyByte[i] = 0xFF;
    }

    Serial.println(F("Scan a MIFARE Classic PICC to demonstrate read and write."));
    Serial.print(F("Using key (for A and B):"));
    dump_byte_array(key.keyByte, MFRC522::MF_KEY_SIZE);
    Serial.println();

    Serial.println(F("BEWARE: Data will be written to the PICC, in sector #1"));
}

/**
 * Main loop.
 */
void loop() {
    // Reset the loop if no new card present on the sensor/reader. This saves the entire process when idle.
    if ( ! mfrc522.PICC_IsNewCardPresent())
        return;

    // Select one of the cards
    if ( ! mfrc522.PICC_ReadCardSerial())
        return;

    // Show some details of the PICC (that is: the tag/card)
    Serial.print(F("Card UID:"));
    dump_byte_array(mfrc522.uid.uidByte, mfrc522.uid.size);
    Serial.println();
    Serial.print(F("PICC type: "));
    MFRC522::PICC_Type piccType = mfrc522.PICC_GetType(mfrc522.uid.sak);
    Serial.println(mfrc522.PICC_GetTypeName(piccType));

    // Check for compatibility
    if (    piccType != MFRC522::PICC_TYPE_MIFARE_MINI
        &&  piccType != MFRC522::PICC_TYPE_MIFARE_1K
        &&  piccType != MFRC522::PICC_TYPE_MIFARE_4K) {
        Serial.println(F("This sample only works with MIFARE Classic cards."));
        return;
    }

    // In this sample we use the second sector,
    // that is: sector #1, covering block #4 up to and including block #7
    byte sector         = 1;
    byte blockAddr      = 4;
    byte dataBlock[]    = {
        0x01, 0x02, 0x03, 0x04, //  1,  2,   3,  4,
        0x05, 0x06, 0x07, 0x08, //  5,  6,   7,  8,
        0x09, 0x0a, 0xff, 0x0b, //  9, 10, 255, 11,
        0x0c, 0x0d, 0x0e, 0x0f  // 12, 13, 14, 15
    };
    byte trailerBlock   = 7;
    MFRC522::StatusCode status;
    byte buffer[18];
    byte size = sizeof(buffer);

    // Authenticate using key A
    Serial.println(F("Authenticating using key A..."));
    status = (MFRC522::StatusCode) mfrc522.PCD_Authenticate(MFRC522::PICC_CMD_MF_AUTH_KEY_A, trailerBlock, &key, &(mfrc522.uid));
    if (status != MFRC522::STATUS_OK) {
        Serial.print(F("PCD_Authenticate() failed: "));
        Serial.println(mfrc522.GetStatusCodeName(status));
        return;
    }

    // Show the whole sector as it currently is
    Serial.println(F("Current data in sector:"));
    mfrc522.PICC_DumpMifareClassicSectorToSerial(&(mfrc522.uid), &key, sector);
    Serial.println();

    // Read data from the block
    Serial.print(F("Reading data from block ")); Serial.print(blockAddr);
    Serial.println(F(" ..."));
    status = (MFRC522::StatusCode) mfrc522.MIFARE_Read(blockAddr, buffer, &size);
    if (status != MFRC522::STATUS_OK) {
        Serial.print(F("MIFARE_Read() failed: "));
        Serial.println(mfrc522.GetStatusCodeName(status));
    }
    Serial.print(F("Data in block ")); Serial.print(blockAddr); Serial.println(F(":"));
    dump_byte_array(buffer, 16); Serial.println();
    Serial.println();

    // Authenticate using key B
    Serial.println(F("Authenticating again using key B..."));
    status = (MFRC522::StatusCode) mfrc522.PCD_Authenticate(MFRC522::PICC_CMD_MF_AUTH_KEY_B, trailerBlock, &key, &(mfrc522.uid));
    if (status != MFRC522::STATUS_OK) {
        Serial.print(F("PCD_Authenticate() failed: "));
        Serial.println(mfrc522.GetStatusCodeName(status));
        return;
    }

    // Write data to the block
    Serial.print(F("Writing data into block ")); Serial.print(blockAddr);
    Serial.println(F(" ..."));
    dump_byte_array(dataBlock, 16); Serial.println();
    status = (MFRC522::StatusCode) mfrc522.MIFARE_Write(blockAddr, dataBlock, 16);
    if (status != MFRC522::STATUS_OK) {
        Serial.print(F("MIFARE_Write() failed: "));
        Serial.println(mfrc522.GetStatusCodeName(status));
    }
    Serial.println();

    // Read data from the block (again, should now be what we have written)
    Serial.print(F("Reading data from block ")); Serial.print(blockAddr);
    Serial.println(F(" ..."));
    status = (MFRC522::StatusCode) mfrc522.MIFARE_Read(blockAddr, buffer, &size);
    if (status != MFRC522::STATUS_OK) {
        Serial.print(F("MIFARE_Read() failed: "));
        Serial.println(mfrc522.GetStatusCodeName(status));
    }
    Serial.print(F("Data in block ")); Serial.print(blockAddr); Serial.println(F(":"));
    dump_byte_array(buffer, 16); Serial.println();
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

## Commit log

2019-05-04 SD Card and HTML FIX
    [main.ino]
2019-05-06 tonuino rewrite
    [config.txt]
2019-08-22 changeing
    change mp3
    files and folders sort
    [Layout.fzz, muster#1.brd, muster#1.sch]
2021-10-27 Initial version
    [Layout.fzz]

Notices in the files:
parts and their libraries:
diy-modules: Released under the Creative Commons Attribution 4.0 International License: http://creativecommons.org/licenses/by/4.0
